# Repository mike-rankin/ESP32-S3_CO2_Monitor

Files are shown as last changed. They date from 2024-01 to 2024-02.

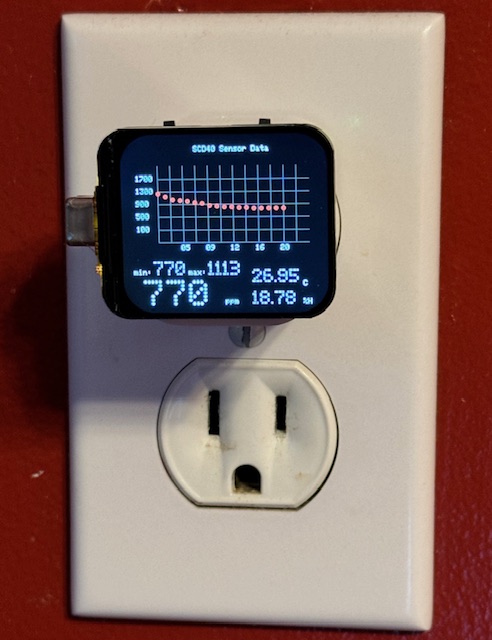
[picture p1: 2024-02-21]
Images/Rev5_Wall.jpg

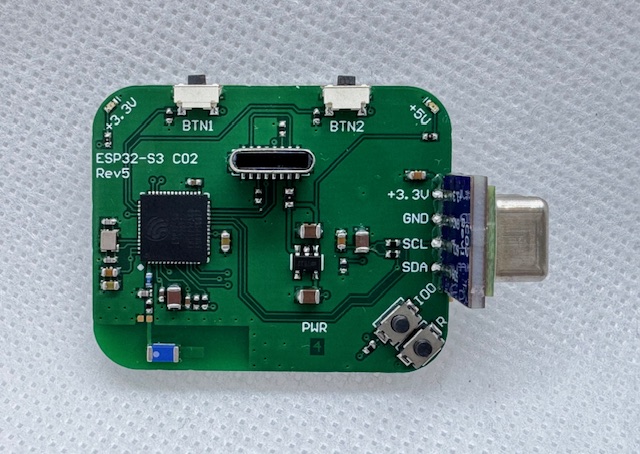
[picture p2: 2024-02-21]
Images/Rev5_Back.jpg

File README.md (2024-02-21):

# ESP32-S3-CO2-Monitor
This is the wall charger mount version of the co2 monitor has been slowly evolving for a while.
It started out as a sensor on qwiic connector but was too messy with the two cables <br/>

Qwiic
The next version elinated the cable. Because of the height of the sensor this version puts it on a seperate board and rear mounts it. From the front side all you see is the tiny hole. It requires a usb-c cable that is on the side and can sit on your desk <br/>
stanoff_back <br/>
stanoff_front <br/>
stanoff_data <br/>
This version uses a make usb-c connector and is design to push onto a wall charger. No cord or cables of any kind required and to upload a new sketch you can plug it into the side of your laptop. <br/>

Plugged_In <br/>
Top <br/>
W_Charger <br/>
Revision 4 has been ordered with a few small changes. Two pushbutton on the lower right for setting the com port are now much smaller. These are only used the once and can be super small. The two pushbutton foorprints for the top buttons are hopefully corrected. A new pushbutton on the bottom will act as a power switch to test out a power switch LTC2954ITS8 that I hope to use in other projects. The device can be turned on and off with a momentaty button instead of a sliding switch and possibly turned off by a gpio pin of the micro. <br/>

The final version, Rev 5 strips away the unnecessary components like the power switch and Qwiic connector for easier assembly and lower cost.  <br/>

Rev5_Back  <br/>
Rev5_with_charger  <br/>
Plugged_In  <br/>

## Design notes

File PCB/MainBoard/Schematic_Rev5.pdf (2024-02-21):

R3 | D- D+
VBUS | B4 VBUS | A9 GND B¹ GND A¹² | GND TAB² GND TAB¹

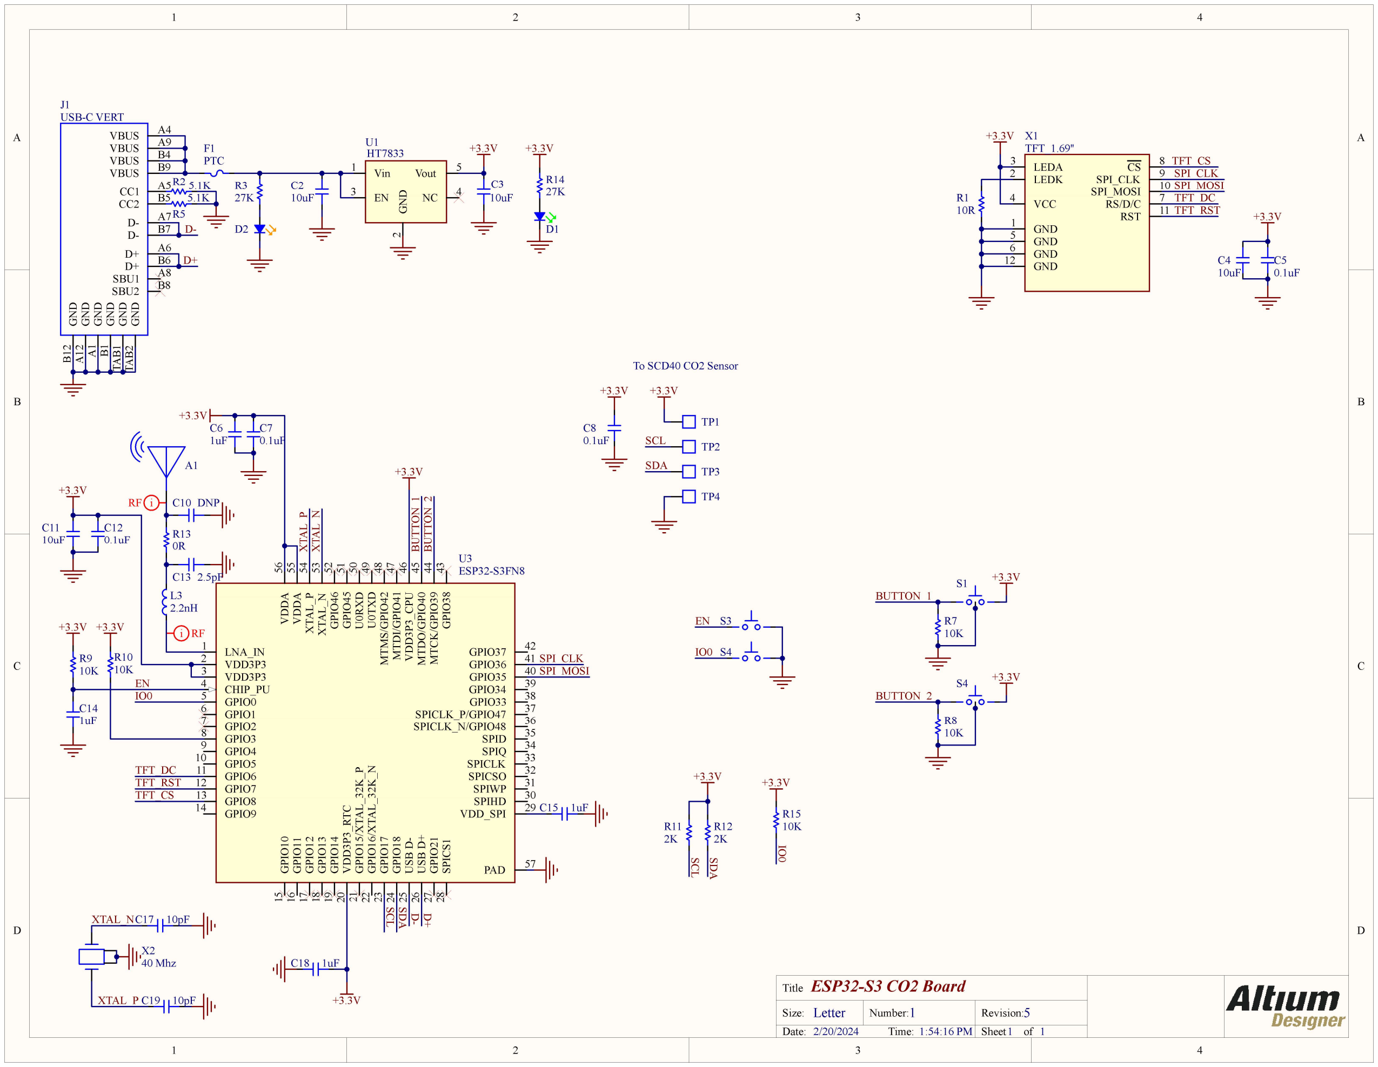
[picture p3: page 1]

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
## ESP32-S3 CO2 Board

1 5
2/20/2024 | 1:54:16 PM

Title

Size: | Number:
Date:

Revision:
Time: | Sheet | of

# Letter IO0

LNA_IN 1

PAD 57

VDD3P3 2
VDD3P3 3
CHIP_PU 4
GPIO0 5
GPIO1 6
GPIO2 7
GPIO3 8
GPIO4 9
GPIO5 10
GPIO6 11
GPIO7 12 | GPIO¹⁰ 15 GPIO¹¹ 16 GPIO¹² 17 GPIO¹³ 18 GPIO¹⁴ 19 VDD³P³_RTC 20 GPIO¹⁵/XTAL_32K_P 21 GPIO¹⁶/XTAL_32K_N 22 GPIO¹⁷ 23 GPIO¹⁸ 24 USB D⁻ 25 USB D⁺ 26
VDD_SPI | 29
SPIWP | 31 SPICSO | 32 SPICLK | 33 SPIQ | 34 SPID | 35 SPICLK_N/GPIO48 | 36 SPICLK_P/GPIO47 | 37 GPIO33 | 38 GPIO34 | 39 GPIO35 | 40 GPIO36 MTCK/GPIO³⁹ | 41 ⁴⁴ MTDO/GPIO⁴⁰ ⁴⁵ VDD³P³_CPU ⁴⁶ MTDI/GPIO⁴¹ ⁴⁷ MTMS/GPIO⁴² ⁴⁸ U⁰TXD ⁴⁹ U⁰RXD ⁵⁰ GPIO⁴⁵ ⁵¹ GPIO⁴⁶ ⁵² XTAL_N ⁵³ XTAL_P ⁵⁴ VDDA ⁵⁵

GPIO8 13
GPIO9 14 | GPIO²¹ 27 SPICS¹ 28
SPIHD | 30
GPIO37 | 42 GPIO³⁸ ⁴³ VDDA ⁵⁶ | ESP32-S3FN8

U3

C15 1uF

+3.3V

+3.3V | XTAL_P XTAL_N

1uF

C6
0.1uF

C7

+3.3V

+3.3V

EN

10K

R9

IO0

+3.3V

40 Mhz | C18 1uF

X2

XTAL_P

XTAL_NC17 10pF

C19 10pF

TFT_RST

1uF

C14

10K

R10

+3.3V

+3.3V

SPI_CLK
SPI_MOSI

D-

D+

PTC

F1

R2 5.1K
5.1K
R5

27K

10uF

C11

2K

R11
2K

R12

+3.3V SCL SDA | SCL SDA

0.1uF

C12

C13 2.5pF

C10 DNP

i RF

RF i

A1

+3.3V

0.1uF

C5
10uF

C4

SPI_CLK
SPI_MOSI

TFT_CS

TFT_RST

TFT_DC

+3.3V

10R

R1

CS | 8
SPI_CLK | 9
SPI_MOSI | 10
RS/D/C | 7
RST | 11

LEDA 3

GND 1

VCC 4

LEDK 2

GND 5
GND 6
GND 12

TFT_1.69"

X1

+3.3V
BUTTON_1

10K

R7

+3.3V
BUTTON_2

10K

R8

TFT_DC

TFT_CS

10K

R15 BUTTON_1 BUTTON_2

L3

# 2.2nH GND A¹ GND B¹²

VBUS | A4
VBUS | B9

USB-C VERT

D+ | B6
SBU2 | B8
CC1 | A5
D- | B7
D+ | A6
D- | A7
SBU1 | A8
CC2 | B5

J1

TP1

TP2

TP4

SCL

SDA

To SCD40 CO2 Sensor

TP3

+3.3V

0.1uF

C8

+3.3V

Vin 1

EN 3 | GND

2

Vout | 5
NC | 4

HT7833

U1

10uF

C3
10uF

C2

+3.3V

0R

R13

S1

S4

D1

27K

R14

+3.3V

D2

S3

IO0 S4

EN

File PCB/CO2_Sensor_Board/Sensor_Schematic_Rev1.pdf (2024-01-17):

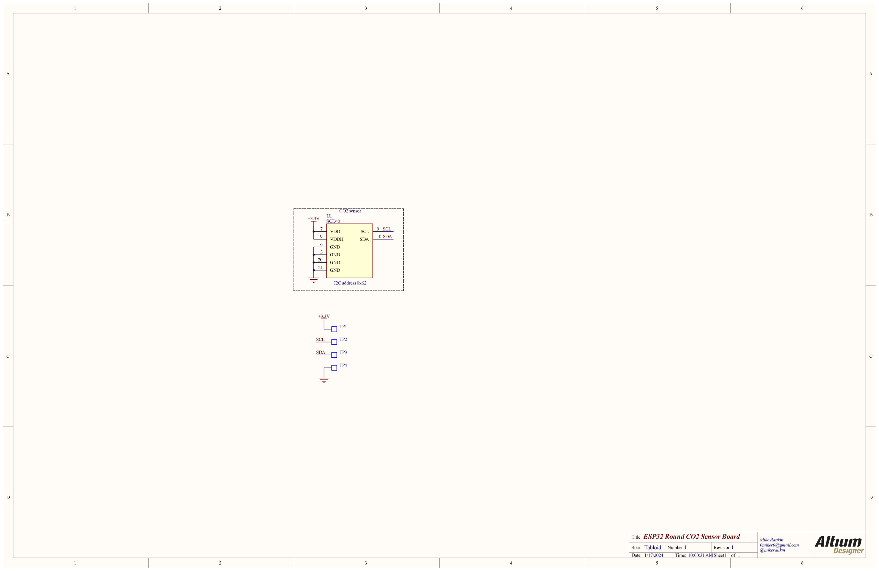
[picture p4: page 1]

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
Mike Rankin
0miker0@gmail.com
@mikerankin
1

## ESP32 Round CO2 Sensor Board

1 1
1/17/2024 | 10:00:31 AM

Title

Size: | Number:
Date:

Revision:
Time: | Sheet | of

### Tabloid

+3.3V

TP1

TP2

TP3

TP4

+3.3V

SCL

SDA

SCD40
VDD 7
VDDH 19
GND 6
GND 3
SDA | 10
SCL | 9

GND 20
GND 21

U1

SCL
SDA

CO2 sensor

I2C address 0x62

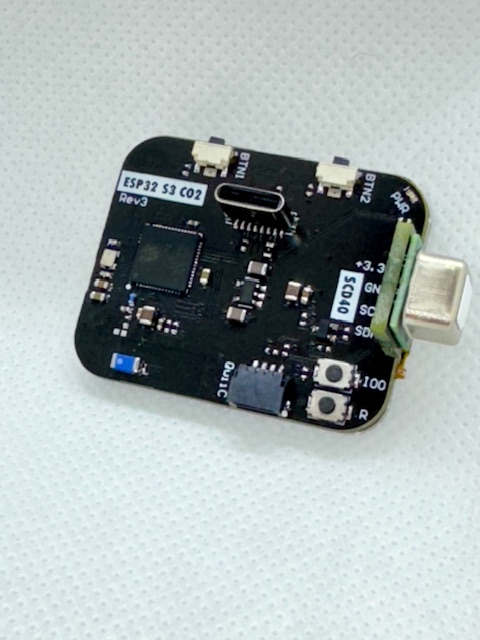
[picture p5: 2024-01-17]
Images/Top.jpg

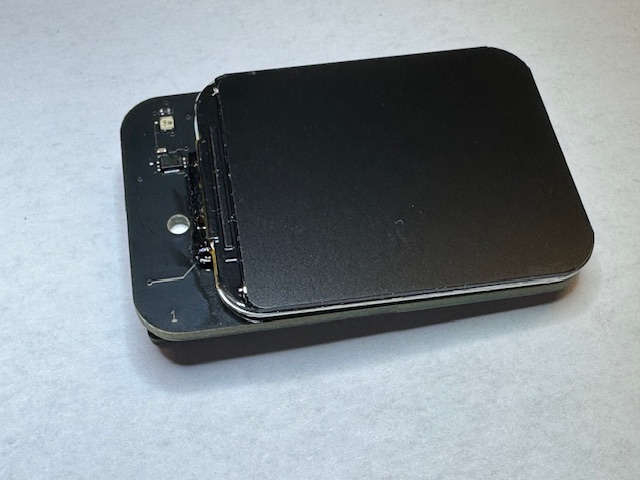
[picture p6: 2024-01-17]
Images/stanoff_front.jpg

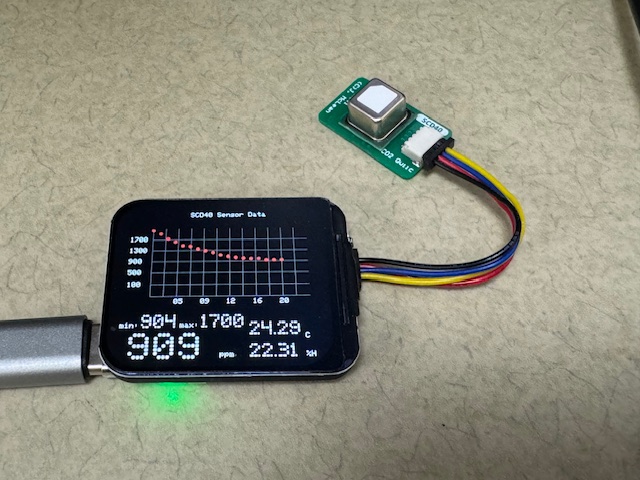
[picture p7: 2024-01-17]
Images/Qwiic.jpg

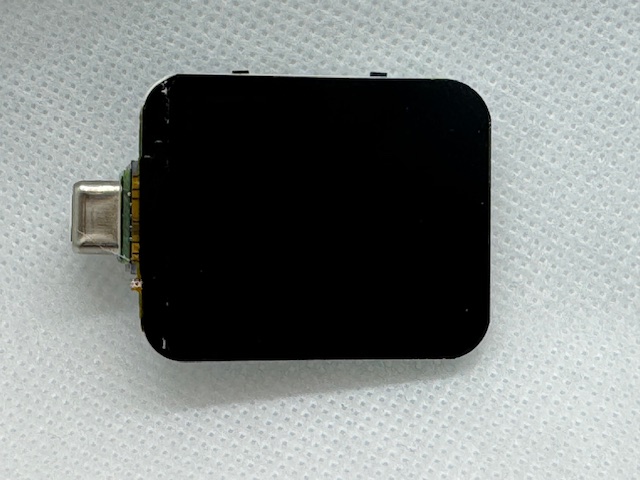
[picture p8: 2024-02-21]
Images/Rev5_Front.jpg

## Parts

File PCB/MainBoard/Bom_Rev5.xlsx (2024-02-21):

Designator | Part_Number | Quantity | Vendor | Description | Manufacturer | Value
A1 | ANT3216LL00R2400A | 1 | LCSC | Antenna Chip 2.4Gig | YAGEO | Chip Antenna
C2, C3, C4, C11 |  | 4 |  | CAP 10uF 50V 0805 |  | 10uF
C5, C7, C8 |  | 3 |  | CAP 0.1uF 0603 |  | 0.1uF
C6, C18 |  | 2 |  | CAP 1uF 0603 |  | 1uF
C10 |  | 1 |  | CAP DNP 0402 |  | DNP
C12 |  | 1 |  | CAP 0.1uF 0402 |  | 0.1uF
C13 |  | 1 |  | CAP 2.5pF 0402 |  | 2.5pF
C14, C15 |  | 2 |  | CAP 1uF 0402 |  | 1uF
C17, C19 |  | 2 |  | CAP 10pF 0402 |  | 10pF
D1 | C74338 | 1 | LCSC | LED Green 0402 |  | Green Led
D2 | C364554 | 1 | LCSC | LED Orange 0402 |  | Orange Led
F1 | C2982257 | 1 | LCSC | PTC FUSE 0.5mA hold, 1A trip 0603 | JDT Fuse | PTC
J1 | C283539 | 1 | LCSC | CONN RECPT USB-C Vertical | Korean Elec | USB-C VERT
L3 |  | 1 |  | Inductor 2.2nH |  | 2.2nH
R1 |  | 1 |  | RES 10R 0402 |  | 10R
R2, R5 |  | 2 |  | RES 5.1K 0402 |  | 5.1K
R3, R14 |  | 2 |  | RES 27K 0402 |  | 27K
R7, R8, R9, R10, R15 |  | 5 |  | RES 10K 0402 |  | 10K
R11, R12 |  | 2 |  | RES 2K 0402 |  | 2K
R13 |  | 1 |  | RES 0R 0402 |  | 0R
S1, S4 | C255808 | 2 | LCSC | SWITCH TACTILE R/A MICRO | HYP | Switch R/A Micro
S3, S4 | TL1015AF160QG | 2 | Digi-Key | SWITCH MOMENTARY
U1 | C164106 | 1 | LCSC | IC LDO 3.3V 0.5A SOT23-5 | Holtek | HT7833
U3 | ESP32-S3FN8 | 1 |  | WIFI/Bluetooth, 8M PSRAM, QFN-56 7x7 | Espressif | ESP32-S3FN8
X1 | LH169TIG01 | 1 | Alibaba | 1.69 INCH TFT SPI Interface |  | TFT_1.69"
X2 | ECS-400-10-37B2-CKM | 1 | Digi-Key | CRYSTAL 40MHZ 10PF SMD | ECS | 40 Mhz

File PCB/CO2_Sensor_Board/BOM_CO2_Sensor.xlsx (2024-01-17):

Designator | Part_Number | Quantity | Vendor | Description | Manufacturer | Value
U1 | SCD40 | 1 |  | CO2 SENSOR 50 PPM I2C SMD | Sensirion | SCD40

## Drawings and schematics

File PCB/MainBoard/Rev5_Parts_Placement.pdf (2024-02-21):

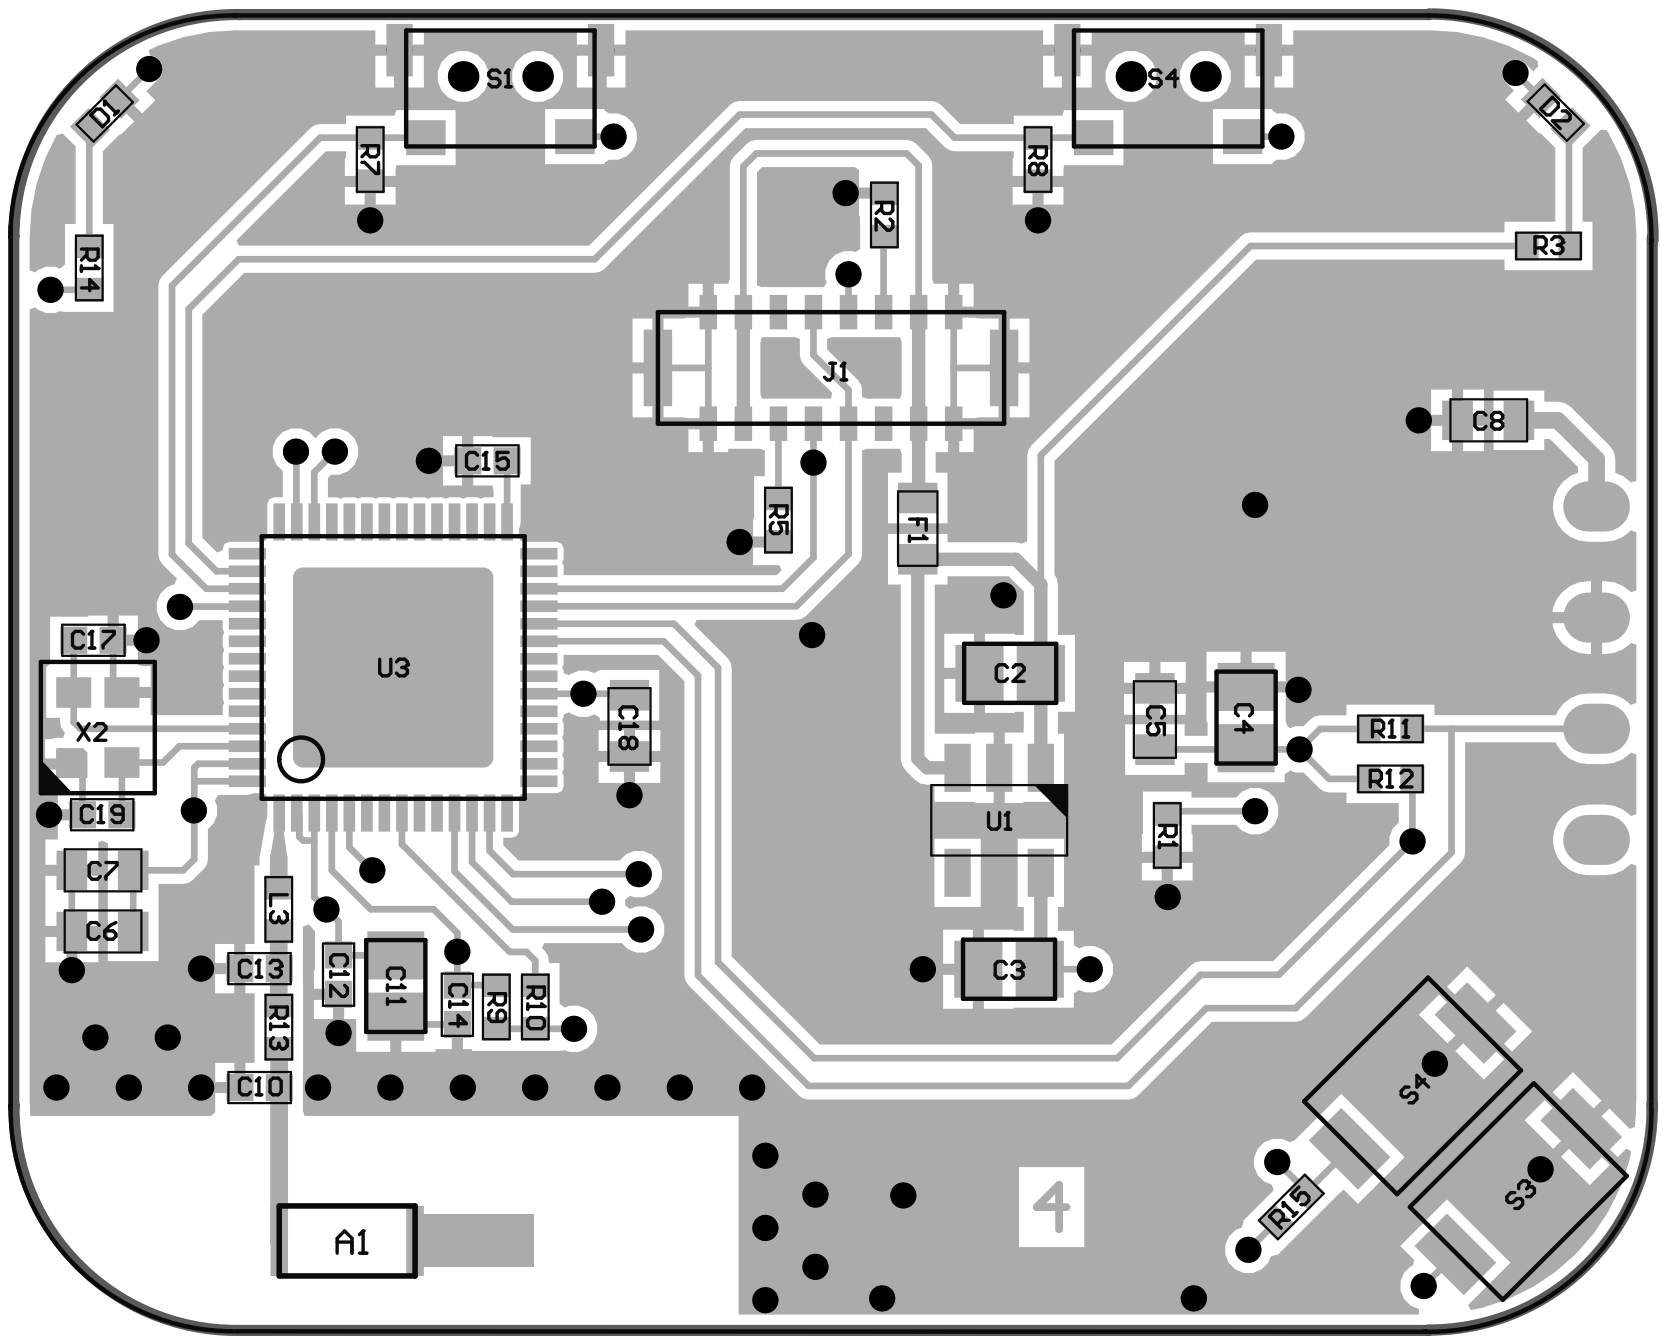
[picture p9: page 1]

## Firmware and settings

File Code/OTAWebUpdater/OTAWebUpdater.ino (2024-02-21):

#include <WiFi.h>
#include <WiFiClient.h>
#include <WebServer.h>
#include <ESPmDNS.h>
#include <Update.h>

const char* host = "ESP32-S3 CO2";
const char* ssid = "XXX";   //XXX
const char* password = "XXX";    //XXX

WebServer server(80);

/*
 * Login page
 */

const char* loginIndex =
 "<form name='loginForm'>"
    "<table width='20%' bgcolor='A09F9F' align='center'>"
        "<tr>"
            "<td colspan=2>"
                "<center><font size=4><b>ESP32 Login Page</b></font></center>"
                "<br>"
            "</td>"
            "<br>"
            "<br>"
        "</tr>"
        "<tr>"
             "<td>Username:</td>"
             "<td><input type='text' size=25 name='userid'><br></td>"
        "</tr>"
        "<br>"
        "<br>"
        "<tr>"
            "<td>Password:</td>"
            "<td><input type='Password' size=25 name='pwd'><br></td>"
            "<br>"
            "<br>"
        "</tr>"
        "<tr>"
            "<td><input type='submit' onclick='check(this.form)' value='Login'></td>"
        "</tr>"
    "</table>"
"</form>"
"<script>"
    "function check(form)"
    "{"
    "if(form.userid.value=='admin' && form.pwd.value=='admin')"
    "{"
    "window.open('/serverIndex')"
    "}"
    "else"
    "{"
    " alert('Error Password or Username')/*displays error message*/"
    "}"
    "}"
"</script>";

/*
 * Server Index Page
 */

const char* serverIndex =
"<script src='https://ajax.googleapis.com/ajax/libs/jquery/3.2.1/jquery.min.js'></script>"
"<form method='POST' action='#' enctype='multipart/form-data' id='upload_form'>"
   "<input type='file' name='update'>"
        "<input type='submit' value='Update'>"
    "</form>"
 "<div id='prg'>progress: 0%</div>"
 "<script>"
  "$('form').submit(function(e){"
  "e.preventDefault();"
  "var form = $('#upload_form')[0];"
  "var data = new FormData(form);"
  " $.ajax({"
  "url: '/update',"
  "type: 'POST',"
  "data: data,"
  "contentType: false,"
  "processData:false,"
  "xhr: function() {"
  "var xhr = new window.XMLHttpRequest();"
  "xhr.upload.addEventListener('progress', function(evt) {"
  "if (evt.lengthComputable) {"
  "var per = evt.loaded / evt.total;"
  "$('#prg').html('progress: ' + Math.round(per*100) + '%');"
  "}"
  "}, false);"
  "return xhr;"
  "},"
  "success:function(d, s) {"
  "console.log('success!')"
 "},"
 "error: function (a, b, c) {"
 "}"
 "});"
 "});"
 "</script>";

/*
 * setup function
 */
void setup(void) {
  Serial.begin(115200);

  // Connect to WiFi network
  WiFi.begin(ssid, password);
  WiFi.setTxPower(WIFI_POWER_13dBm);  //Needed ???
  Serial.println("");

  // Wait for connection
  while (WiFi.status() != WL_CONNECTED) {
    delay(500);
    Serial.print(".");
  }
  Serial.println("");
  Serial.print("Connected to ");
  Serial.println(ssid);
  Serial.print("IP address: ");
  Serial.println(WiFi.localIP());

  /*use mdns for host name resolution*/
  if (!MDNS.begin(host)) { //http://esp32.local
    Serial.println("Error setting up MDNS responder!");
    while (1) {
      delay(1000);
    }
  }
  Serial.println("mDNS responder started");
  /*return index page which is stored in serverIndex */
  server.on("/", HTTP_GET, []() {
    server.sendHeader("Connection", "close");
    server.send(200, "text/html", loginIndex);
  });
  server.on("/serverIndex", HTTP_GET, []() {
    server.sendHeader("Connection", "close");
    server.send(200, "text/html", serverIndex);
  });
  /*handling uploading firmware file */
  server.on("/update", HTTP_POST, []() {
    server.sendHeader("Connection", "close");
    server.send(200, "text/plain", (Update.hasError()) ? "FAIL" : "OK");
    ESP.restart();
  }, []() {
    HTTPUpload& upload = server.upload();
    if (upload.status == UPLOAD_FILE_START) {
      Serial.printf("Update: %s\n", upload.filename.c_str());
      if (!Update.begin(UPDATE_SIZE_UNKNOWN)) { //start with max available size
        Update.printError(Serial);
      }
    } else if (upload.status == UPLOAD_FILE_WRITE) {
      /* flashing firmware to ESP*/
      if (Update.write(upload.buf, upload.currentSize) != upload.currentSize) {
        Update.printError(Serial);
      }
    } else if (upload.status == UPLOAD_FILE_END) {
      if (Update.end(true)) { //true to set the size to the current progress
        Serial.printf("Update Success: %u\nRebooting...\n", upload.totalSize);
      } else {
        Update.printError(Serial);
      }
    }
  });
  server.begin();
}

void loop(void) {
  server.handleClient();
  delay(1);
}

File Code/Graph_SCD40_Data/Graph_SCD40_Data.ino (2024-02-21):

#include <SensirionI2CScd4x.h>
#include "Arduino.h"
#include "TFT_eSPI.h"
#include <Wire.h>
#include "DotFont.h"          //larger LED Dot-Matrix
#include "Smaller_DotFont.h"  //smaller LED Dot-Matrix

SensirionI2CScd4x scd4x;
TFT_eSPI tft = TFT_eSPI();
TFT_eSprite sprite = TFT_eSprite(&tft);

int values[24]={0};
int values2[24]={0};
char timeHour[3]="00";
char timeMin[3]="00";
char timeSec[3];

char m[12];
char y[5];
char d[3];
char dw[12];

int gw=204;  //204
int gh=102;  //102
int gx=50;   //position of graph across
int gy=144;  //144
int curent=0;
#define gray 0x6B6D
#define darkgrey  0x4208 
#define blue 0x0967
#define orange 0xC260
#define purple 0x604D
#define green 0x1AE9

int deb=0;
int Mode=0;

void setup(void)
{
  uint16_t error;
  char errorMessage[256];

  Serial.begin(115200);
  Wire.begin(18,17);
  scd4x.begin(Wire);
  tft.init();
  tft.fillScreen(TFT_BLACK);
  tft.setRotation(3);
    
  sprite.createSprite(280, 240); 
  sprite.setTextDatum(3);
  sprite.setSwapBytes(true);
  values[23]=gh/2;
  analogReadResolution(10);

  // stop potentially previously started measurement
  error = scd4x.stopPeriodicMeasurement();
  if (error) 
  {
   Serial.print("Error trying to execute stopPeriodicMeasurement(): ");
  }

  // Start Measurement
  error = scd4x.startPeriodicMeasurement();
  if (error) 
  {
   Serial.print("Error trying to execute startPeriodicMeasurement(): ");
   errorToString(error, errorMessage, 256);
   Serial.println(errorMessage);
  }
}

int counter=0;
int Min=gh/2;
int Max=gh/2;
int average=0;
String minT="";
String maxT="";

uint16_t co2;
uint16_t co2_min = 5000;  //too high a value
uint16_t co2_max = 10;    //too low a value

String co2_min_text;
String co2_max_text;

String co2_text;
String temp_text;
String humid_text;
float temperature = 0.0f;
float humidity = 0.0f;

void loop()
{
 uint16_t error;
 char errorMessage[256];
 delay(100);

 bool isDataReady = false;
 error = scd4x.getDataReadyFlag(isDataReady);

 sprite.fillSprite(TFT_BLACK);

 for(int i=1;i<12;i++)
 {
  sprite.drawLine(gx+(i*17),gy,gx+(i*17),gy-gh,darkgrey);
  if(i*17%34==0)
  if(i*2<10)
  sprite.drawString("0"+String((i*2)+1),gx+(i*17)-3,gy+8);  //Bottom 04,08,12,16,20
  else
  sprite.drawString(String(i*2),gx+(i*17)-4,gy+8);  //Bottom,4,8
 }
  
 for(int i=1;i<6;i++)
 {
  sprite.drawLine(gx,gy-(i*17),gx+gw,gy-(i*17),darkgrey);
  sprite.drawString(String(i*400-300),gx-30,gy-(i*17)); //Left side numbers, 
 }

  sprite.drawLine(gx,gy,gx+gw,gy,darkgrey);  //Bottom line
  sprite.drawLine(gx,gy,gx,gy-gh,darkgrey);  //Left side line

 if (error) 
 {
  Serial.print("Error trying to execute getDataReadyFlag(): ");
  errorToString(error, errorMessage, 256);
  Serial.println(errorMessage);
  return;
 }

 if (!isDataReady) 
 {
  return;
 }

 error = scd4x.readMeasurement(co2, temperature, humidity);

 if (error) 
 {
  Serial.print("Error trying to execute readMeasurement(): ");
  errorToString(error, errorMessage, 256);
  Serial.println(errorMessage);
  } 

  else if (co2 == 0) 
  {
   Serial.println("Invalid sample detected, skipping.");
  } 
  else
  {
  
   for(int i=0;i<21;i++)  
   {
    co2_text=co2;
    temp_text=temperature;
    humid_text=humidity;
    scd4x.readMeasurement(co2, temperature, humidity);
    if (co2 > 1700)
    {
     co2=1700;
    }
    else
    {
    }

    sprite.fillCircle(gx+(i*10), gy-(co2/17), 2, TFT_RED); 
    //Serial.println(co2/100);
    sprite.loadFont(DotFont);
    sprite.fillRect(10, 165, 250, 70, TFT_BLACK); //Black out old CO2 value, (10, 175, 250, 70
    sprite.setTextColor(TFT_WHITE, TFT_BLACK); 
    sprite.drawString(co2_text,25,215);
    sprite.unloadFont();
    sprite.loadFont(Smaller_DotFont);
    sprite.drawString(temp_text,175,190);
    sprite.drawString(humid_text,175,220);
    sprite.unloadFont();
  
    sprite.drawString("SCD40 Sensor Data",100,20);
    sprite.drawString(" C",240,200);
    sprite.drawString(" %H",240,225);
    sprite.drawString("ppm",140,225);
    sprite.drawString("min:",15,185);
    sprite.drawString("max:",90,185);

    //calculate co2 min and max
    if (co2<co2_min)
    co2_min = co2;
    Serial.print("Min:");
    Serial.println(co2_min);

    if (co2>co2_max)
    co2_max = co2;
    Serial.print("Max:");
    Serial.println(co2_max);

    co2_max_text=co2_max;
    co2_min_text=co2_min;
    sprite.loadFont(Smaller_DotFont);
    sprite.drawString(co2_max_text,115,180);
    sprite.drawString(co2_min_text,40,180);
    sprite.unloadFont();   
    sprite.pushSprite(0,0);
    delay(10000);
   }

   sprite.pushSprite(0,0);
  }

}

 
